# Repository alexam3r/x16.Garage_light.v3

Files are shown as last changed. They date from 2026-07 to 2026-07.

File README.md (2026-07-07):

# Гаражный свет на ESP8266

Прошивка для управления светом в гараже на базе ESP8266 (Wemos D1 mini).
Среда разработки — PlatformIO + Arduino framework, язык C++.

Устройство подключается к Wi-Fi и MQTT-брокеру, управляет двумя группами света
(основное освещение и декоративные лампы Эдисона) в двух взаимоисключающих
режимах, реагирует на PIR-датчик движения и раз в минуту публикует JSON-статус
с показаниями датчика температуры/влажности.

## Аппаратная часть

- **Контроллер:** Wemos D1 mini (ESP8266).
- **Питание:** БП 220VAC → 5VDC.
- **Реле:** плата с двумя электромеханическими реле (основное + Edison).
- **Датчики:** AM2320 (температура/влажность, I²C) и PIR (движение).

### Распиновка

| Пин | GPIO | Функция |
| --- | ---- | --- |
| D5  | GPIO14 | Основное освещение (реле 1) |
| D6  | GPIO12 | Декоративные лампы Эдисона (реле 2) |
| D7  | GPIO13 | PIR — датчик движения |
| D1  | GPIO5  | I²C SDA → AM2320 |
| D2  | GPIO4  | I²C SCL → AM2320 |

AM2320 питается от 3.3V; PIR и реле-плата — по своей логике (обычно 5V с общим GND).

## Возможности

- **PIR-автоматика:** при обнаружении движения свет включается на 10 минут;
  повторное срабатывание обнуляет таймер. Триггер — по фронту LOW→HIGH.
- **MQTT-управление:** команда `light/set ON` включает свет на 1 час.
- **Два режима света** (`mode`): `main` (D5) и `edison` (D6), взаимоисключающие.
  Команда `mode/set edison` при выключенном свете включает свет в режиме edison
  на 1 час; при горящем свете — переключает активную лампу, не трогая таймер.
- **Сброс при выключении:** когда свет гаснет (таймер истёк или `light/set OFF`),
  режим возвращается на `main`. Реакцией на PIR это не управляет — она задаётся
  только `motion/set` (с авто-возвратом через 6 часов).
- **Отключаемая реакция на PIR:** `motion/set OFF` — PIR перестаёт включать свет,
  но факт движения продолжает публиковаться в `motion/state`. Состояние самой
  реакции (вкл/выкл) отдаётся отдельным retain-топиком `motion/enabled` — чтобы
  клиенты (например Home Assistant) получали его мгновенно, без ожидания статуса.
  Реакция сама включается обратно через 6 часов (`MOTION_AUTO_ENABLE_MS`) — сброс
  к дефолту на случай, если ушёл из гаража и забыл вернуть; `motion/set ON`
  отменяет авто-возврат.
- **JSON-статус** в топике `status`: состояние света, режим, факт движения,
  включена ли реакция на PIR, температура, влажность, uptime, уровень Wi-Fi сигнала.
  Публикуется раз в минуту, а при изменении любого параметра состояния (свет,
  режим, движение, реакция на PIR) — немедленно, с обнулением минутного таймера
  (чтобы не слать статус дважды подряд).
- **Watchdog:** если Wi-Fi и MQTT одновременно отсутствуют 10 минут —
  устройство перезагружается (`ESP.restart()`). Аппаратный watchdog core ESP8266
  защищает от зависаний.

## Настройка

1. Скопируйте `src/Secrets.h.sample` в `src/Secrets.h` и заполните реальные значения:
   - `WIFI_SSID`, `WIFI_PASSWORD` — Wi-Fi сеть;
   - `MQTT_HOST` — IP/hostname брокера;
   - `MQTT_USER`, `MQTT_PASSWORD` — креды брокера (пусто = без auth);
   - `MQTT_CLIENT_ID` — уникальный ID клиента.
2. При необходимости отредактируйте `src/Config.h`:
   - `RELAY_ACTIVE_HIGH` — полярность реле (`1` = HIGH включает; если реле
     срабатывает «наоборот» — поставьте `0`);
   - `LIGHT_TIMEOUT_PIR_MS` / `LIGHT_TIMEOUT_MQTT_MS` — длительности таймера;
   - `CFG_ENABLE_AM2320` — `0`, если датчик не подключён (temp/humidity = `null`).
3. `Secrets.h` исключён из git (`.gitignore`) — не коммитить креды.

## Сборка и прошивка

```bash
# только компиляция (проверка сборки)
pio run

# компиляция + прошивка устройства через USB
pio run -t upload

# монитор последовательного порта (115200)
pio device monitor
```

## MQTT-топики

Корень дерева — `garage/light`.

| Топик | Направление | Payload | Retain | Назначение |
| --- | --- | --- | --- | --- |
| `garage/light/availability` | out | `online`/`offline` | да | LWT + статус на коннекте |
| `garage/light/light/set` | in | `ON`/`OFF` | — | команда включения/выключения |
| `garage/light/light/state` | out | `ON`/`OFF` | да | текущее состояние света |
| `garage/light/mode/set` | in | `main`/`edison` | — | команда выбора режима |
| `garage/light/mode/state` | out | `main`/`edison` | да | текущий режим |
| `garage/light/motion/set` | in | `ON`/`OFF` | — | включить/выключить реакцию на PIR |
| `garage/light/motion/state` | out | `ON`/`OFF` | нет | факт обнаружения движения (по фронту) |
| `garage/light/motion/enabled` | out | `ON`/`OFF` | да | состояние реакции на PIR (вкл/выкл) |
| `garage/light/status` | out | JSON | да | статус устройства (раз в минуту + при изменении состояния) |

### Пример JSON статуса

```json
{"light":"on","mode":"main","motion":"off","motion_enabled":"on","temperature":23.4,"humidity":55.0,"uptime":3600,"wifi_rssi":-67}
```

- `motion` — факт обнаружения движения PIR прямо сейчас (`on`/`off`).
- `motion_enabled` — включена ли реакция на PIR (`on`/`off`; `off` после `motion/set OFF`,
  сам вернётся в `on` через 6 часов).

При недоступном датчике: `"temperature":null,"humidity":null`.

## Проверка через mosquitto

```bash
# подписка на все топики устройства
mosquitto_sub -h <broker> -t 'garage/light/#' -v

# включить свет
mosquitto_pub -h <broker> -t 'garage/light/light/set' -m 'ON'

# выключить свет
mosquitto_pub -h <broker> -t 'garage/light/light/set' -m 'OFF'

# включить режим Edison (при выключенном свете — включит свет в edison на 1 час)
mosquitto_pub -h <broker> -t 'garage/light/mode/set' -m 'edison'

# отключить реакцию на PIR (сама включится через 6 часов)
mosquitto_pub -h <broker> -t 'garage/light/motion/set' -m 'OFF'

# вернуть реакцию на PIR вручную (отменяет авто-возврат)
mosquitto_pub -h <broker> -t 'garage/light/motion/set' -m 'ON'
```

## Логика таймера и режимов

- **Один таймер выключения** + флаг источника (`PIR` или `MQTT`).
- PIR при выключенном свете → включение на `LIGHT_TIMEOUT_PIR_MS` (10 мин), источник `PIR`.
- PIR при включённом свете → обнуление таймера на длительность **текущего**
  источника (PIR → 10 мин, MQTT → 1 час). Источник переключается только явной
  MQTT-командой (`light/set ON` или `mode/set`); PIR не переподчиняет MQTT-сеанс.
- `light/set ON` → источник `MQTT`, таймер 1 час.
- `mode/set` при горящем свете → переключение лампы, таймер не меняется.
- `mode/set` при выключенном свете → включение в выбранном режиме на 1 час.
- Выключение (таймер или `light/set OFF`) → режим `main`; реакция на PIR не меняется.
- `motion/set OFF` → реакция на PIR выключена; через `MOTION_AUTO_ENABLE_MS` (6 ч)
  включается сама. `motion/set ON` включает сразу и отменяет авто-возврат.

## Troubleshooting

- **`temperature`/`humidity` = `null`** — датчик AM2320 не отвечает. Проверьте
  подключение SDA/SCL (D1/D2), питание 3.3V, подтяжки I²C (4.7kΩ к 3.3V, если
  на модуле их нет). Для отладки логики без датчика поставьте `CFG_ENABLE_AM2320=0`.
- **Реле щёлкает «наоборот»** (ON выключает свет) — инвертируйте `RELAY_ACTIVE_HIGH`
  в `Config.h`.
- **PIR не срабатывает** — попробуйте `PIR_PIN_MODE INPUT_PULLUP` в `Config.h`
  (если датчик с открытым коллектором); проверьте питание PIR.
- **MQTT не подключается** — смотрите `mqtt.state()` в Serial-логе: `-2` = не удалось
  подключиться, `-4` = неверный логин/пароль, `2` = ID клиента занят.
- **Устройство перезагружается** — если Wi-Fi/MQTT отсутствуют 10 минут, это
  срабатывает connectivity-watchdog (нормально); если чаще — проверьте питание
  (brownout от индуктивных выбросов реле) и стабильность сети.

## Структура файлов

| Файл | Назначение |
| --- | --- |
| `src/main.cpp` | Вся логика: `setup()` + `loop()`, Wi-Fi/MQTT, свет, PIR, AM2320. |
| `src/Config.h` | Пины, константы времени, MQTT-дефолты, переключатели `CFG_ENABLE_*`. |
| `src/Secrets.h` | Wi-Fi/MQTT креды (в `.gitignore`, редактируется под устройство). |
| `src/Secrets.h.sample` | Шаблон секретов (в git). |
| `platformio.ini` | Окружение сборки PlatformIO. |
| `architecture.md` | Описание архитектуры и логики. |
| `README.md` | Этот файл. |

## Подробности архитектуры

См. [`architecture.md`](architecture.md) — блок-схема, конечный автомат света,
логика таймера/режимов, watchdog-уровни, MQTT-дерево и ограничения.

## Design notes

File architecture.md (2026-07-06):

# Архитектура прошивки гаражного света

## Обзор

ESP8266 (Wemos D1 mini) управляет двумя группами света по MQTT и PIR-датчику,
публикует статус и поддерживает автономность через watchdog-и. Вся логика — в
`src/main.cpp`; конфигурация в `src/Config.h`, креды в `src/Secrets.h`.

## Блок-схема

```
   ┌─────────┐     ┌───────────┐     ┌───────────────┐     ┌──────────────┐
   │  Wi-Fi  │────▶│   MQTT    │────▶│ onMqttMessage │────▶│  Действия    │
   │ connect │     │  connect  │     │   (callback)  │     │ turnLight*  │
   └─────────┘     │  + LWT    │     └───────────────┘     │ applyMode   │
                   │  + subs   │                           │ extendTimer │
                   └─────┬─────┘                           └──────┬───────┘
                         │ publish (retain)                       │
                         ▼                                        │
                  ┌───────────────┐    ┌────────────┐              │
                  │  MQTT-топики  │◀───│  pollPir   │◀─────────────┘
                  │  state/status │    │ (front)    │
                  └───────────────┘    └────────────┘
```

`loop()` неблокирующий: держит Wi-Fi/MQTT, опрашивает PIR, ведёт таймер света,
читает AM2320 в кэш, раз в минуту публикует JSON, проверяет connectivity-watchdog.

## Конечный автомат света

Свет описывается тремя величинами: `lightState` (on/off), `currentSource`
(`SRC_NONE`/`SRC_PIR`/`SRC_MQTT`) и `currentMode` (`MODE_MAIN`/`MODE_EDISON`).
Один таймер `lightOffAt` (deadline в `millis()`).

| Событие | Условие | Действие |
| --- | --- | --- |
| PIR-фронт LOW→HIGH | свет выключен, `motionEnabled` | `turnLightOn(PIR, mode)` — таймер 10 мин |
| PIR-фронт LOW→HIGH | свет горит, `motionEnabled` | `extendTimer()` — обнулить на длительность текущего источника |
| `light/set ON` | любое | `turnLightOn(MQTT, mode)` — источник MQTT, таймер 1 час |
| `light/set OFF` | любое | `turnLightOff()` — выключить, `mode→main`, `motionEnabled→true` |
| `mode/set X` | свет горит | `applyMode(X)` — переключить лампу, таймер/источник не трогать |
| `mode/set X` | свет выключен | `turnLightOn(MQTT, X)` — включить в режиме X на 1 час |
| `motion/set OFF` | любое | `motionEnabled=false` (без публикации флага) |
| Таймер истёк | `lightOffAt` прошёл | `turnLightOff()` |
| PIR-фронт (любой) | всегда | `publishMotionState()` (факт движения, без retain) |

### Роль источника в продлении таймера

`extendTimer()` ставит таймер на длительность **текущего** источника:
- `SRC_PIR` → `LIGHT_TIMEOUT_PIR_MS` (10 мин);
- `SRC_MQTT` → `LIGHT_TIMEOUT_MQTT_MS` (1 час).

Источник меняется только явной MQTT-командой. PIR не переподчиняет MQTT-сеанс —
если свет включён по MQTT на час, PIR лишь продлевает на час (не на 10 минут).

### `mode/set` — диаграмма решений

```
mode/set <X>
   │
   ├── свет горит? ─── ДА ──▶ applyMode(X) + publishModeState()
   │                            (таймер и источник не меняются)
   │
   └── НЕТ ───────────────▶ turnLightOn(MQTT, X)
                                (включить в режиме X на 1 час)
```

При любом выключении режим сбрасывается на `main` (в `turnLightOff()`).

## PIR: debounce и развязка «наблюдение vs реакция»

Опрос в `pollPir()` каждый цикл `loop()`:

1. Сырое чтение изменилось → перезапуск debounce-таймера, выход.
2. Сырое чтение стабильно, отличается от зафиксированного, debounce (`PIR_DEBOUNCE_MS`) истёк → фиксация фронта.
3. На любой фронт → `publishMotionState()` (факт движения).
4. Фронт LOW→HIGH: если `motionEnabled` — реакция (включение/продление света); если `!motionEnabled` — только публикация.

**Развязка:** `motion/state` (факт движения) публикуется всегда, независимо от
`motionEnabled`. `motionEnabled` влияет только на включение света. Это позволяет
наблюдать активность датчика даже при отключённой реакции.

Флаг `motionEnabled` намеренно **не публикуется** ни в каком retain-топике — это
разовая команда; сбрасывается в ON при выключении света; при рестарте — default ON.

## MQTT-дерево

Корень `garage/light`. Направление: `in` — подписка (команды), `out` — публикация.

| Топик | Напр. | Retain | Payload |
| --- | --- | --- | --- |
| `availability` | out | да | `online`/`offline` |
| `light/set` | in | — | `ON`/`OFF` |
| `light/state` | out | да | `ON`/`OFF` |
| `mode/set` | in | — | `main`/`edison` |
| `mode/state` | out | да | `main`/`edison` |
| `motion/set` | in | — | `ON`/`OFF` (флаг реакции) |
| `motion/state` | out | **нет** | `ON`/`OFF` (факт движения) |
| `status` | out | да | JSON (раз в минуту) |

**LWT:** в `connectMqtt()` регистрируется will-сообщение `availability=offline`
(retain). При корректной связи мы публикуем `availability=online` на коннекте.
При обрыве связи брокер сам публикует `offline`.

**Порядок в `connectMqtt()`:** подписки на `set`-топики → публикация актуального
состояния. Мы не подписаны на собственные `state`-топики, поэтому echo своих
retained не превращается в команды.

## Глобальные переменные

| Переменная | Тип | Назначение |
| --- | --- | --- |
| `lightState` | `bool` | свет вкл/выкл |
| `currentMode` | `LightMode` | `MODE_MAIN`/`MODE_EDISON` |
| `currentSource` | `LightSource` | `SRC_NONE`/`SRC_PIR`/`SRC_MQTT` |
| `lightOffAt` | `unsigned long` | deadline выключения (`millis()+timeout`), 0 = неактивен |
| `pirStable`/`pirRawLast`/`pirDebounceTs` | `bool`/`bool`/`unsigned long` | debounce PIR |
| `motionEnabled` | `bool` | реакция на PIR |
| `sensorOk`/`lastTemp`/`lastHum`/`lastSensorRead` | — | кэш AM2320 |
| `lastWifiAttempt`/`lastMqttAttempt`/`lastStatusPub` | `unsigned long` | тайминги loop |
| `lastAllOkTs` | `unsigned long` | connectivity watchdog |
| `statusBuf[256]` | `char[]` | буфер JSON-статуса |

## Порядок `setup()`

1. Serial (115200).
2. Пины реле → OUTPUT, `applyRelay(*, false)` (безопасное стартовое состояние).
3. PIR → `pinMode`, чтение начального состояния в `pirStable`/`pirRawLast`.
4. `WiFi.persistent(false)`, `WiFi.mode(WIFI_STA)`.
5. `Wire.begin(I2C_SDA, I2C_SCL)` — **до** `am2320.begin()`.
6. `am2320.begin()` (если `CFG_ENABLE_AM2320`).
7. `mqtt.setServer`/`setCallback`/`setBufferSize(512)`.
8. `lastAllOkTs = millis()` (база connectivity watchdog).
9. `connectWifi()` — первая попытка.

## Цикл `loop()`

1. Неблокирующий реконнект Wi-Fi (раз в `WIFI_RECONNECT_DELAY_MS`).
2. Неблокирующий реконнект MQTT (раз в `MQTT_RECONNECT_DELAY_MS`, только при Wi-Fi).
3. `mqtt.loop()` — только если подключены.
4. `pollPir()` — каждый цикл.
5. `handleLightTimer()` — каждый цикл.
6. `readAm2320()` — обновление кэша раз в `SENSOR_READ_INTERVAL_MS`.
7. `publishStatusJson()` — раз в `STATUS_INTERVAL_MS` (только при MQTT).
8. Connectivity watchdog (см. ниже).

## Watchdog — два уровня

### 1. Connectivity watchdog (программный)

`lastAllOkTs` обновляется каждый цикл, если `WiFi.status()==WL_CONNECTED &&
mqtt.connected()`. Если с момента последнего «всё ОК» прошло `CONNECT_TIMEOUT_MS`
(10 минут) — `ESP.restart()`. Работает параллельно с реконнектами, не блокирует их.

### 2. Аппаратный watchdog (core ESP8266)

ESP8266 core содержит два watchdog-таймера — software (SDK) и hardware
(финальная защита). Оба активны по умолчанию; их нужно регулярно «кормить»,
иначе — перезагрузка. Кормление происходит через:
- `yield()` / `delay()` — отдаёт управление Wi-Fi-стеку и кормит WDT;
- `mqtt.loop()`.

В долгих местах явно вызывается `yield()`: перед/после чтения AM2320
(I²C-транзакция ~0.5–1 с), после сборки JSON. `applyMode()` содержит
`delay(RELAY_SWITCH_DELAY_MS)`, который также кормит WDT и защищает от
индуктивного выброса реле. Отдельный `ESP.wdtEnable()` не используется —
core-WDT достаточен.

## Разностная форма `millis()` (защита от переполнения)

`millis()` переполняется через ~49.7 дней. Сравнение `millis() >= deadline`
**некорректно** при переполнении (deadline близко к концу цикла, `millis()`
обнулился). Вместо этого используется разностная арифметика `unsigned long`:

```
(millis() - lastXxx) >= INTERVAL
```

При переполнении разность `(unsigned long)(now - prev)` благодаря modular
арифметике даёт корректное значение. Все таймеры в `loop()` и `handleLightTimer()`
используют эту форму. `handleLightTimer()` дополнительно проверяет `lightOffAt != 0`.

## AM2320 — кэш-паттерн

Чтение датчика (~0.5–1 с с wake-up) вынесено из публикации статуса:
`readAm2320()` обновляет кэш `lastTemp`/`lastHum` раз в
`SENSOR_READ_INTERVAL_MS` (20 с), а `publishStatusJson()` публикует из кэша —
мгновенно. Валидация: `isnan()` + sanity-диапазон (`TEMP_MIN..TEMP_MAX`,
`HUM_MIN..HUM_MAX`); при ошибке — `NAN` → в JSON `null`. `Wire.begin()` вызывается
до `am2320.begin()` (библиотека не инициализирует Wire сама).

## JSON-статус

Топик `garage/light/status`, retain, раз в 60 с. Сборка через `dtostrf` +
конкатенация (без зависимости от float-printf). Поля:
`light`, `mode`, `motion`, `temperature`, `humidity`, `uptime`, `wifi_rssi`.
Недоступный датчик → `null`. Сборка в `statusBuf[256]` (вписывается в
`MQTT_MAX_PACKET_SIZE=512`).

## Безопасность и ограничения

- **Нет Home Assistant discovery** — только `set`/`state`/`availability` + JSON.
- **Нет OTA** — прошивка только по USB (`pio run -t upload`).
- **Нет persistence** — состояние сбрасывается при рестарте (свет выкл, режим
  `main`, `motionEnabled=true`); retained-сообщения обновляются при коннекте.
- **`cleanSession=true`** (PubSubClient default) — нет persistent session,
  очередь команд брокером не хранится.
- **Секреты не в git** — `Secrets.h` в `.gitignore`.
- **MQTT payload** — в `onMqttMessage` копируется в локальный буфер с нулём-
  терминатором перед парсингом (`byte*` не нуль-терминирован).
- **Публикация внутри callback** безопасна — payload уже скопирован; подписки
  выполняются только в `connectMqtt()`, не в callback.

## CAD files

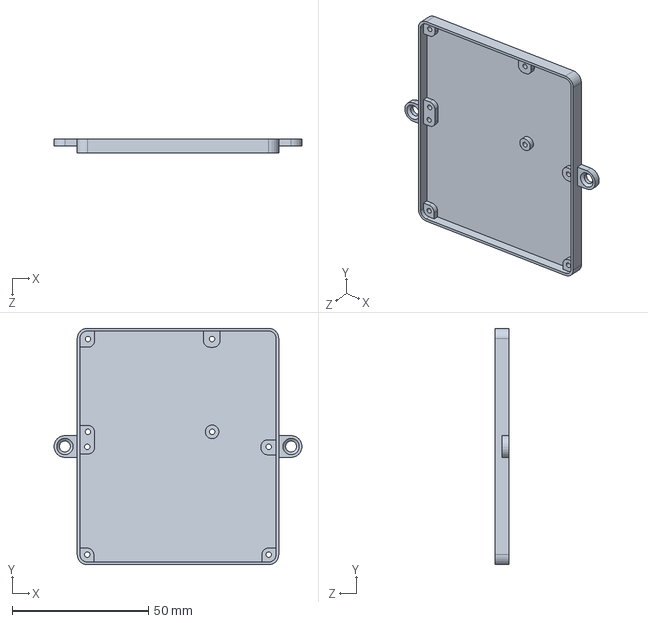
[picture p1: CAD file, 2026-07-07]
Altium/box_Mech.SLDPRT
90.9 x 86.7 x 5.00 mm

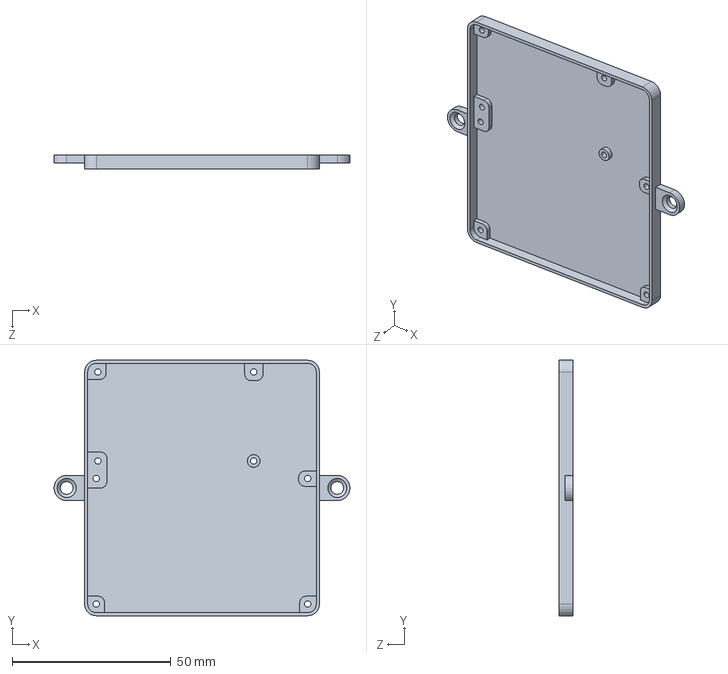
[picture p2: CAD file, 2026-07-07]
Altium/box_SSR.SLDPRT
93.1 x 80.4 x 4.50 mm

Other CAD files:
Altium/box_Mech.STL

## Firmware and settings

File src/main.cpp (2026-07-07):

// =============================================================================
// Прошивка гаражного света на ESP8266 (Wemos D1 mini).
//
// Назначение: управление двумя группами света (основная D5 / декоративная
// Edison D6) в двух взаимоисключающих режимах, с автоматикой по PIR-датчику,
// MQTT-командами, минутным JSON-статусом и отключаемой реакцией на движение.
//
// Вся логика ведётся в этом файле. Конфиг — Config.h, креды — Secrets.h.
// =============================================================================

#include <Arduino.h>
#include <ESP8266WiFi.h>
#include <PubSubClient.h>
#include <Wire.h>

#include "Config.h"   // должен идти ДО условного include AM2320 (содержит CFG_ENABLE_AM2320)
#include "Secrets.h"

#if CFG_ENABLE_AM2320
#include <Adafruit_AM2320.h>
#endif

// -----------------------------------------------------------------------------
// Глобальные объекты
// -----------------------------------------------------------------------------
WiFiClient     espClient;
PubSubClient   mqtt(espClient);
#if CFG_ENABLE_AM2320
Adafruit_AM2320 am2320;
#endif

// -----------------------------------------------------------------------------
// Режимы и источники света
// -----------------------------------------------------------------------------
enum LightMode   : uint8_t { MODE_MAIN = 0, MODE_EDISON = 1 };
enum LightSource : uint8_t { SRC_NONE = 0, SRC_PIR = 1, SRC_MQTT = 2 };

// -----------------------------------------------------------------------------
// Состояние
// -----------------------------------------------------------------------------
// Свет и таймер
bool          lightState    = false;   // вкл/выкл
LightMode     currentMode   = MODE_MAIN;
LightSource   currentSource = SRC_NONE;
unsigned long lightOffAt    = 0;       // deadline выключения (millis()+timeout), 0 = таймер неактивен

// PIR (опрос с антидребезгом по фронту)
bool          pirStable     = false;   // стабильное состояние после debounce
bool          pirRawLast    = false;   // последнее «сырое» чтение пина
unsigned long pirDebounceTs = 0;       // когда последний раз видели изменение
bool          motionEnabled = true;    // реакция на PIR (motion/set ON/OFF)
unsigned long motionEnableAt = 0;      // deadline авто-возврата реакции, 0 = таймер неактивен

// AM2320 (кэш значений — чтение развязано с публикацией статуса)
#if CFG_ENABLE_AM2320
bool          sensorOk      = false;
float         lastTemp      = NAN;
float         lastHum       = NAN;
unsigned long lastSensorRead = 0;
#endif

// Тайминги loop()
unsigned long lastWifiAttempt = 0;
unsigned long lastMqttAttempt = 0;
unsigned long lastStatusPub   = 0;
bool          statusDirty     = false;  // состояние изменилось — статус уйдёт немедленно

// Connectivity watchdog: последний момент, когда и Wi-Fi, и MQTT были подключены.
unsigned long lastAllOkTs     = 0;

// Буфер для JSON-статуса
char statusBuf[256];

// -----------------------------------------------------------------------------
// Прототипы функций
// -----------------------------------------------------------------------------
void applyRelay(uint8_t pin, bool on);
void applyMode(LightMode mode);
void turnLightOn(LightSource src, LightMode mode);
void turnLightOff();
void extendTimer();
void handleLightTimer();
void handleMotionTimer();
void pollPir();
void readAm2320();
void handleLightSet(const char* cmd);
void handleModeSet(const char* cmd);
void handleMotionSet(const char* cmd);
void onMqttMessage(char* topic, byte* payload, unsigned int length);
bool connectWifi();
bool connectMqtt();
void publishAvailability(bool online);
void publishLightState();
void publishModeState();
void publishMotionState();
void publishMotionEnabledState();
void publishStatusJson();

// =============================================================================
// Реле и режимы
// =============================================================================

// Инкапсулирует полярность управления реле.
void applyRelay(uint8_t pin, bool on) {
    digitalWrite(pin, RELAY_ACTIVE_HIGH ? on : !on);
}

// Зажигает пин активного режима, второй гасит. Режимы взаимоисключающие.
// Пауза между гашением и зажиганием — защита от индуктивного выброса реле.
void applyMode(LightMode mode) {
    applyRelay(PIN_LIGHT_MAIN, false);
    applyRelay(PIN_LIGHT_EDISON, false);
    delay(RELAY_SWITCH_DELAY_MS);   // также кормит core WDT
    if (mode == MODE_MAIN) {
        applyRelay(PIN_LIGHT_MAIN, true);
    } else {
        applyRelay(PIN_LIGHT_EDISON, true);
    }
    currentMode = mode;
}

// =============================================================================
// Логика света и таймера
// =============================================================================

// Включить свет от источника src в режиме mode, поставить таймер выключения.
void turnLightOn(LightSource src, LightMode mode) {
    currentSource = src;
    unsigned long timeout = (src == SRC_PIR) ? LIGHT_TIMEOUT_PIR_MS : LIGHT_TIMEOUT_MQTT_MS;
    lightOffAt  = millis() + timeout;
    lightState  = true;
    applyMode(mode);
    publishLightState();
    publishModeState();
    statusDirty = true;

    Serial.print(F("Light ON  src="));
    Serial.print(src == SRC_PIR ? F("PIR") : F("MQTT"));
    Serial.print(F(" mode="));
    Serial.print(mode == MODE_MAIN ? PAYLOAD_MODE_MAIN : PAYLOAD_MODE_EDISON);
    Serial.print(F(" timeout_ms="));
    Serial.println(timeout);
}

// Выключить свет, сбросить источник и режим на main.
// Реле гасятся напрямую (без applyMode — тот повторно зажёг бы реле режима).
// Флаг motionEnabled НЕ трогаем: реакция на PIR управляется только motion/set.
void turnLightOff() {
    lightState    = false;
    currentSource = SRC_NONE;
    lightOffAt    = 0;
    currentMode   = MODE_MAIN;   // режим по умолчанию (логически, без энергизации реле)
    applyRelay(PIN_LIGHT_MAIN, false);
    applyRelay(PIN_LIGHT_EDISON, false);
    publishLightState();
    publishModeState();
    statusDirty = true;

    Serial.println(F("Light OFF, mode reset to main"));
}

// Обнулить таймер на длительность текущего источника (PIR -> 10 мин, MQTT -> 1 ч).
void extendTimer() {
    if (!lightState) return;     // нечего продлевать
    unsigned long timeout = (currentSource == SRC_PIR) ? LIGHT_TIMEOUT_PIR_MS : LIGHT_TIMEOUT_MQTT_MS;
    lightOffAt = millis() + timeout;

    Serial.print(F("Timer extended to "));
    Serial.print(timeout);
    Serial.print(F(" ms (source="));
    Serial.print(currentSource == SRC_PIR ? F("PIR") : F("MQTT"));
    Serial.println(')');
}

// Проверка истечения таймера выключения. Разностная форма корректна через
// переполнение millis() (~49.7 дней).
void handleLightTimer() {
    if (lightOffAt == 0) return;
    if ((long)(millis() - lightOffAt) >= 0) {
        Serial.println(F("Timer expired"));
        turnLightOff();
    }
}

// =============================================================================
// PIR (опрос с антидребезгом по фронту)
// =============================================================================

void pollPir() {
    bool rawNow = digitalRead(PIN_PIR);

    // Сырое чтение изменилось — перезапускаем debounce-таймер.
    if (rawNow != pirRawLast) {
        pirRawLast    = rawNow;
        pirDebounceTs = millis();
        return;
    }

    // Сырое чтение стабильно и отличается от зафиксированного состояния,
    // debounce истёк — фиксируем новый фронт.
    if (rawNow != pirStable && (millis() - pirDebounceTs) >= PIR_DEBOUNCE_MS) {
        bool prev = pirStable;
        pirStable = rawNow;

        // Факт движения публикуем всегда (развязка «наблюдение vs реакция»).
        publishMotionState();
        statusDirty = true;

        // Фронт LOW -> HIGH: движение началось.
        if (!prev && pirStable) {
            Serial.println(F("PIR: motion START"));
            if (motionEnabled) {
                if (!lightState) {
                    turnLightOn(SRC_PIR, currentMode);   // свет был выключен — включаем на 10 мин
                } else {
                    extendTimer();                        // свет горит — обнуляем таймер текущего источника
                }
            } else {
                Serial.println(F("  motion disabled, no action"));
            }
        } else if (prev && !pirStable) {
            // Фронт HIGH -> LOW: движение закончилось — только публикация (уже сделана).
            Serial.println(F("PIR: motion END"));
        }
    }
}

// =============================================================================
// AM2320 (кэш значений)
// =============================================================================

void readAm2320() {
#if CFG_ENABLE_AM2320
    if (!sensorOk) return;
    if ((millis() - lastSensorRead) < SENSOR_READ_INTERVAL_MS) return;
    lastSensorRead = millis();

    yield();   // кормит core WDT перед долгим I²C-чтением (~0.5–1 с)
    float t = am2320.readTemperature();
    float h = am2320.readHumidity();
    yield();

    // Валидация: isnan + sanity-диапазон.
    if (!isnan(t) && t >= TEMP_MIN && t <= TEMP_MAX) {
        lastTemp = t;
    } else {
        lastTemp = NAN;
    }
    if (!isnan(h) && h >= HUM_MIN && h <= HUM_MAX) {
        lastHum = h;
    } else {
        lastHum = NAN;
    }

    if (isnan(lastTemp) || isnan(lastHum)) {
        Serial.println(F("AM2320: read failed"));
    }
#endif
}

// =============================================================================
// Обработка MQTT-команд
// =============================================================================

void handleLightSet(const char* cmd) {
    if (strcasecmp(cmd, PAYLOAD_ON) == 0) {
        turnLightOn(SRC_MQTT, currentMode);
    } else if (strcasecmp(cmd, PAYLOAD_OFF) == 0) {
        turnLightOff();
    } else {
        Serial.print(F("light/set: unknown payload: "));
        Serial.println(cmd);
    }
}

void handleModeSet(const char* cmd) {
    LightMode target;
    if (strcasecmp(cmd, PAYLOAD_MODE_MAIN) == 0) {
        target = MODE_MAIN;
    } else if (strcasecmp(cmd, PAYLOAD_MODE_EDISON) == 0) {
        target = MODE_EDISON;
    } else {
        Serial.print(F("mode/set: unknown payload: "));
        Serial.println(cmd);
        return;
    }

    if (lightState) {
        // Свет горит — переключить активный пин, таймер и источник не трогать.
        applyMode(target);
        publishModeState();
        statusDirty = true;
        Serial.print(F("Mode switched (light on) -> "));
        Serial.println(target == MODE_MAIN ? PAYLOAD_MODE_MAIN : PAYLOAD_MODE_EDISON);
    } else {
        // Свет выключен — включить в выбранном режиме на 1 час (источник MQTT).
        turnLightOn(SRC_MQTT, target);
    }
}

void handleMotionSet(const char* cmd) {
    if (strcasecmp(cmd, PAYLOAD_ON) == 0) {
        motionEnabled  = true;
        motionEnableAt = 0;          // авто-возврат больше не нужен
        Serial.println(F("Motion reaction: ON"));
    } else if (strcasecmp(cmd, PAYLOAD_OFF) == 0) {
        motionEnabled  = false;
        motionEnableAt = millis() + MOTION_AUTO_ENABLE_MS;   // сам включится через 6 ч
        Serial.println(F("Motion reaction: OFF (auto-enable in 6h)"));
    } else {
        Serial.print(F("motion/set: unknown payload: "));
        Serial.println(cmd);
        return;
    }
    // Состояние реакции публикуем отдельным retain-топиком (без задержки статуса).
    publishMotionEnabledState();
    statusDirty = true;
}

// Авто-возврат реакции на PIR: если её отключили и прошло MOTION_AUTO_ENABLE_MS,
// снова включаем (сброс к дефолту). Разностная форма корректна через overflow millis().
void handleMotionTimer() {
    if (motionEnableAt == 0) return;
    if ((long)(millis() - motionEnableAt) >= 0) {
        motionEnabled  = true;
        motionEnableAt = 0;
        Serial.println(F("Motion reaction: auto-enabled after timeout"));
        publishMotionEnabledState();
        statusDirty = true;
    }
}

void onMqttMessage(char* topic, byte* payload, unsigned int length) {
    if (!mqtt.connected()) return;
    if (length == 0) return;   // пустой payload игнорируем

    // payload не нуль-терминирован — копируем в локальный буфер с '\0'.
    char buf[16];
    size_t n = (length < sizeof(buf) - 1) ? length : (sizeof(buf) - 1);
    memcpy(buf, payload, n);
    buf[n] = '\0';

    Serial.print(F("[MQTT] "));
    Serial.print(topic);
    Serial.print(F(" => "));
    Serial.println(buf);

    // Роутинг по топику. Публикации внутри callback безопасны — payload уже скопирован.
    if (strcmp(topic, TOPIC_LIGHT_SET) == 0) {
        handleLightSet(buf);
    } else if (strcmp(topic, TOPIC_MODE_SET) == 0) {
        handleModeSet(buf);
    } else if (strcmp(topic, TOPIC_MOTION_SET) == 0) {
        handleMotionSet(buf);
    }
}

// =============================================================================
// Подключение Wi-Fi и MQTT
// =============================================================================

bool connectWifi() {
    if (WiFi.status() == WL_CONNECTED) return true;

    Serial.print(F("Wi-Fi: connecting to "));
    Serial.println(WIFI_SSID);

    // WiFi.mode/ persistent уже выставлены в setup().
    WiFi.begin(WIFI_SSID, WIFI_PASSWORD);

    // Ждём подключения ~10 секунд (20 × 500 мс).
    uint8_t attempts = 0;
    while (WiFi.status() != WL_CONNECTED && attempts++ < 20) {
        delay(500);
        Serial.print('.');
    }
    Serial.println();

    if (WiFi.status() == WL_CONNECTED) {
        Serial.print(F("Wi-Fi: connected, IP="));
        Serial.println(WiFi.localIP());
        return true;
    }

    Serial.println(F("Wi-Fi: connection failed"));
    return false;
}

bool connectMqtt() {
    Serial.print(F("MQTT: connecting to "));
    Serial.print(MQTT_HOST);
    Serial.print(':');
    Serial.println(MQTT_PORT);

    // LWT: при потере связи брокер сам опубликует availability=offline (retain).
    bool ok;
    if (strlen(MQTT_USER) > 0) {
        ok = mqtt.connect(MQTT_CLIENT_ID, MQTT_USER, MQTT_PASSWORD,
                          TOPIC_AVAILABILITY, 0, true, PAYLOAD_OFFLINE);
    } else {
        ok = mqtt.connect(MQTT_CLIENT_ID, nullptr, nullptr,
                          TOPIC_AVAILABILITY, 0, true, PAYLOAD_OFFLINE);
    }

    if (!ok) {
        Serial.print(F("MQTT: failed, rc="));
        Serial.println(mqtt.state());   // 4 = bad creds, -2 = connect failed, ...
        return false;
    }

    Serial.println(F("MQTT: connected"));

    // Сначала подписки, затем публикация состояния — чтобы не получить собственные
    // retained обратно как команды (мы не подписаны на state-топики).
    mqtt.subscribe(TOPIC_LIGHT_SET);
    mqtt.subscribe(TOPIC_MODE_SET);
    mqtt.subscribe(TOPIC_MOTION_SET);
    Serial.println(F("MQTT: subscribed to set-topics"));

    // Публикуем актуальное состояние (retain, кроме motion/state).
    publishAvailability(true);
    publishLightState();
    publishModeState();
    publishMotionState();
    publishMotionEnabledState();
    statusDirty = true;   // свежий статус сразу после (пере)подключения
    return true;
}

// =============================================================================
// Публикации
// =============================================================================

void publishAvailability(bool online) {
    if (!mqtt.connected()) return;
    mqtt.publish(TOPIC_AVAILABILITY, online ? PAYLOAD_ONLINE : PAYLOAD_OFFLINE, true);
}

void publishLightState() {
    if (!mqtt.connected()) return;
    mqtt.publish(TOPIC_LIGHT_STATE, lightState ? PAYLOAD_ON : PAYLOAD_OFF, true);
}

void publishModeState() {
    if (!mqtt.connected()) return;
    mqtt.publish(TOPIC_MODE_STATE,
                 currentMode == MODE_MAIN ? PAYLOAD_MODE_MAIN : PAYLOAD_MODE_EDISON, true);
}

// Факт движения — без retain (публикация только по фронту).
void publishMotionState() {
    if (!mqtt.connected()) return;
    mqtt.publish(TOPIC_MOTION_STATE, pirStable ? PAYLOAD_ON : PAYLOAD_OFF, false);
}

// Состояние реакции на PIR — retain (HA читает мгновенно, без ожидания статуса).
void publishMotionEnabledState() {
    if (!mqtt.connected()) return;
    mqtt.publish(TOPIC_MOTION_ENABLED, motionEnabled ? PAYLOAD_ON : PAYLOAD_OFF, true);
}

// JSON-статус (раз в минуту + немедленно при изменении состояния): light, mode,
// motion, motion_enabled, temperature, humidity, uptime, wifi_rssi.
// Сборка через dtostrf + конкатенация — без зависимости от float-printf.
void publishStatusJson() {
    if (!mqtt.connected()) return;

    char num[12];

    strcpy(statusBuf, "{\"light\":\"");
    strcat(statusBuf, lightState ? "on" : "off");
    strcat(statusBuf, "\",\"mode\":\"");
    strcat(statusBuf, currentMode == MODE_MAIN ? "main" : "edison");
    strcat(statusBuf, "\",\"motion\":\"");
    strcat(statusBuf, pirStable ? "on" : "off");
    strcat(statusBuf, "\",\"motion_enabled\":\"");
    strcat(statusBuf, motionEnabled ? "on" : "off");
    strcat(statusBuf, "\",\"temperature\":");

#if CFG_ENABLE_AM2320
    if (isnan(lastTemp)) {
        strcat(statusBuf, "null");
    } else {
        dtostrf(lastTemp, 2, 1, num);
        strcat(statusBuf, num);
    }
#else
    strcat(statusBuf, "null");
#endif
    strcat(statusBuf, ",\"humidity\":");
#if CFG_ENABLE_AM2320
    if (isnan(lastHum)) {
        strcat(statusBuf, "null");
    } else {
        dtostrf(lastHum, 2, 1, num);
        strcat(statusBuf, num);
    }
#else
    strcat(statusBuf, "null");
#endif

    strcat(statusBuf, ",\"uptime\":");
    utoa((unsigned)(millis() / 1000UL), num, 10);
    strcat(statusBuf, num);

    strcat(statusBuf, ",\"wifi_rssi\":");
    int rssi = WiFi.RSSI();
    if (WiFi.status() == WL_CONNECTED) {
        itoa(rssi, num, 10);
        strcat(statusBuf, num);
    } else {
        strcat(statusBuf, "null");
    }
    strcat(statusBuf, "}");

    yield();
    mqtt.publish(TOPIC_STATUS, statusBuf, true);
}

// =============================================================================
// setup / loop
// =============================================================================

void setup() {
    Serial.begin(115200);
    delay(100);
    Serial.println();
    Serial.println(F("=== Garage light (ESP8266) ==="));

    // Пины реле — выходы, безопасное стартовое состояние (выключено).
    pinMode(PIN_LIGHT_MAIN, OUTPUT);
    pinMode(PIN_LIGHT_EDISON, OUTPUT);
    applyRelay(PIN_LIGHT_MAIN, false);
    applyRelay(PIN_LIGHT_EDISON, false);

    // PIR.
    pinMode(PIN_PIR, PIR_PIN_MODE);
    pirStable  = digitalRead(PIN_PIR);
    pirRawLast = pirStable;

    // Wi-Fi: только STA, без записи в flash при каждом begin.
    WiFi.persistent(false);
    WiFi.mode(WIFI_STA);

    // I²C для AM2320 (Wire.begin ДО am2320.begin()).
    Wire.begin(I2C_SDA, I2C_SCL);

#if CFG_ENABLE_AM2320
    sensorOk = am2320.begin();
    Serial.print(F("AM2320: "));
    Serial.println(sensorOk ? F("initialized") : F("not found"));
#else
    Serial.println(F("AM2320: disabled (CFG_ENABLE_AM2320=0)"));
#endif

    // MQTT.
    mqtt.setServer(MQTT_HOST, MQTT_PORT);
    mqtt.setCallback(onMqttMessage);
    mqtt.setBufferSize(MQTT_BUFFER_SIZE);

    lastAllOkTs = millis();   // базовая точка для connectivity watchdog

    connectWifi();            // первый запуск — пробуем сразу
}

void loop() {
    unsigned long now = millis();

    // --- Неблокирующее восстановление Wi-Fi ---
    if (WiFi.status() != WL_CONNECTED) {
        if ((now - lastWifiAttempt) >= WIFI_RECONNECT_DELAY_MS) {
            lastWifiAttempt = now;
            connectWifi();
        }
    }

    // --- Неблокирующее восстановление MQTT ---
    if (WiFi.status() == WL_CONNECTED && !mqtt.connected()) {
        if ((now - lastMqttAttempt) >= MQTT_RECONNECT_DELAY_MS) {
            lastMqttAttempt = now;
            if (connectMqtt()) {
                lastMqttAttempt = 0;   // сразу ретраить при следующем сбое
            }
        }
    }

    // --- Обработка входящих MQTT-пакетов ---
    if (mqtt.connected()) {
        mqtt.loop();
    }

    // --- Основная логика ---
    pollPir();
    handleLightTimer();
    handleMotionTimer();
    readAm2320();

    // --- JSON-статус: раз в минуту либо немедленно при изменении состояния.
    // Немедленная отправка обнуляет минутный таймер — без дублей подряд.
    if (mqtt.connected() && (statusDirty || (millis() - lastStatusPub) >= STATUS_INTERVAL_MS)) {
        statusDirty   = false;
        lastStatusPub = millis();
        publishStatusJson();
    }

    // --- Connectivity watchdog: 10 минут без Wi-Fi+MQTT -> restart ---
    if (WiFi.status() == WL_CONNECTED && mqtt.connected()) {
        lastAllOkTs = millis();
    } else if ((millis() - lastAllOkTs) >= CONNECT_TIMEOUT_MS) {
        Serial.println(F("Watchdog: no Wi-Fi+MQTT for 10 min, restarting..."));
        delay(200);   // успеть отправить лог
        ESP.restart();
    }
}

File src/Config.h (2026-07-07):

#pragma once

// =============================================================================
// Конфигурация прошивки гаражного света (ESP8266, Wemos D1 mini).
// Здесь НЕТ секретов — креды лежат в Secrets.h.
// =============================================================================

// -----------------------------------------------------------------------------
// Пины (распиновка Wemos D1 mini)
// -----------------------------------------------------------------------------
#define PIN_LIGHT_MAIN     D5   // GPIO14 — основное освещение (реле 1)
#define PIN_LIGHT_EDISON   D6   // GPIO12 — декоративные лампы Эдисона (реле 2)
#define PIN_PIR            D7   // GPIO13 — датчик движения (PIR)

#define I2C_SDA            D2   // GPIO4 — I²C SDA (AM2320)
#define I2C_SCL            D1   // GPIO5 — I²C SCL (AM2320)

// -----------------------------------------------------------------------------
// Реле
// -----------------------------------------------------------------------------
// Полярность управления реле. 1: HIGH = включено (active-HIGH модуль);
// 0: LOW = включено (active-LOW модуль). Инвертируется в applyRelay().
#define RELAY_ACTIVE_HIGH       1
// Пауза между гашением одного реле и зажиганием другого при переключении
// режима — защита от индуктивного выброса и brownout ESP8266.
#define RELAY_SWITCH_DELAY_MS   10

// -----------------------------------------------------------------------------
// PIR (датчик движения)
// -----------------------------------------------------------------------------
// INPUT — для PIR с активным выходом (HC-SR501 и клоны).
// Если сигнал плавает (открытый коллектор) — заменить на INPUT_PULLUP.
#define PIR_PIN_MODE            INPUT
#define PIR_DEBOUNCE_MS         50   // антидребезг PIR, мс
// Авто-возврат реакции на PIR: если её отключили командой motion/set OFF,
// через это время реакция сама включится (сброс к дефолту, если ушёл из гаража).
#define MOTION_AUTO_ENABLE_MS   21600000UL   // 6 часов

// -----------------------------------------------------------------------------
// Таймеры света
// -----------------------------------------------------------------------------
#define LIGHT_TIMEOUT_PIR_MS    600000UL    // 10 минут — источник PIR
#define LIGHT_TIMEOUT_MQTT_MS   3600000UL   // 1 час   — источник MQTT

// -----------------------------------------------------------------------------
// Интервалы loop()
// -----------------------------------------------------------------------------
#define STATUS_INTERVAL_MS      60000UL     // публикация JSON-статуса раз в минуту
#define SENSOR_READ_INTERVAL_MS 20000UL     // обновление кэша AM2320 (>= 2 с минимум датчика)
#define WIFI_RECONNECT_DELAY_MS 10000UL     // задержка между попытками Wi-Fi
#define MQTT_RECONNECT_DELAY_MS 5000UL      // задержка между попытками MQTT
#define CONNECT_TIMEOUT_MS      600000UL    // connectivity watchdog: 10 минут без Wi-Fi+MQTT -> ESP.restart()

// -----------------------------------------------------------------------------
// MQTT
// -----------------------------------------------------------------------------
#define MQTT_BUFFER_SIZE        512         // PubSubClient::setBufferSize()
#define MQTT_PORT               1883

// -----------------------------------------------------------------------------
// Топики (корень garage/light, одно устройство)
// -----------------------------------------------------------------------------
#define TOPIC_AVAILABILITY      "garage/light/availability"   // retain: online/offline (LWT)
#define TOPIC_LIGHT_SET         "garage/light/light/set"      // cmd: ON/OFF
#define TOPIC_LIGHT_STATE       "garage/light/light/state"    // retain: ON/OFF
#define TOPIC_MODE_SET          "garage/light/mode/set"       // cmd: main/edison
#define TOPIC_MODE_STATE        "garage/light/mode/state"     // retain: main/edison
#define TOPIC_MOTION_SET        "garage/light/motion/set"     // cmd: ON/OFF (enable/disable реакции)
#define TOPIC_MOTION_STATE      "garage/light/motion/state"   // без retain: ON/OFF факт движения
#define TOPIC_MOTION_ENABLED    "garage/light/motion/enabled" // retain: ON/OFF состояние реакции на PIR
#define TOPIC_STATUS            "garage/light/status"         // retain: JSON раз в минуту

// -----------------------------------------------------------------------------
// Payload-константы
// -----------------------------------------------------------------------------
#define PAYLOAD_ON              "ON"
#define PAYLOAD_OFF             "OFF"
#define PAYLOAD_ONLINE          "online"
#define PAYLOAD_OFFLINE         "offline"
#define PAYLOAD_MODE_MAIN       "main"
#define PAYLOAD_MODE_EDISON     "edison"
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

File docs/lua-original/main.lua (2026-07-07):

function createLightTimer()
    if not lightTimer then
        lightTimer = tmr.create()
        lightTimer:register(dat.lightTimeout*1000, tmr.ALARM_SINGLE, function() 
            light("OFF")
            destroyLightTimer()
            dat.lightSelected = 'MAIN'
            table.insert(topub, {'lightSelected', dat.lightSelected})
        end)
        lightTimer:start()
    else
        lightTimer:stop()
        lightTimer:interval(dat.lightTimeout*1000)
        lightTimer:start()
    end
end

function destroyLightTimer()
    if(lightTimer) then
        lightTimer:stop()
        lightTimer:unregister()
        lightTimer = nil
    end
end

function createMoveDetectionTimer()
    if not moveDetectionTimer then
        moveDetectionTimer = tmr.create()
        moveDetectionTimer:register(dat.moveDetectionTimout, tmr.ALARM_SINGLE, function() -- (6870947) 1:54:30.947
            gpio.trig(pinPIR, "up", moveDetected)
            dat.lightSelected = 'MAIN'
            table.insert(topub, {'lightSelected', dat.lightSelected})
            dat.lightMoveDetection = 'ON'
            table.insert(topub, {'lightMoveDetection', dat.lightMoveDetection})
            destroyMoveDetectionTimer()
        end)
        moveDetectionTimer:start()
    else
        moveDetectionTimer:stop()
        moveDetectionTimer:interval(dat.moveDetectionTimout) --6870947
        moveDetectionTimer:start()
    end
end

function destroyMoveDetectionTimer()
    if(moveDetectionTimer) then
        moveDetectionTimer:stop()
        moveDetectionTimer:unregister()
        moveDetectionTimer = nil
    end
end

function light(_light)
    if dat.lightNow ~= _light then
        table.insert(topub, {'lightNow', _light})
    end
    dat.lightNow = _light
    if dat.lightNow == "ON" then
        if dat.lightSelected == 'MAIN' then
            gpio.write(pinLightMain,1)
            gpio.write(pinLightEdison,0)
        else
            gpio.write(pinLightMain,0)
            gpio.write(pinLightEdison,1)
        end
        createLightTimer()
        print('Light ON')
    else
        print('Light OFF')
        if dat.lightSelected == 'MAIN' then
            gpio.write(pinLightMain,0)
        else
            gpio.write(pinLightEdison,0)
        end
        dat.light = 'OFF'
        table.insert(topub, {'light', dat.light})
        destroyLightTimer()
    end
end

function moveDetected()
    print("MOVE!!!")
    if dat.lightNow == "ON" then
        createLightTimer()
    else
        dat.lightTimeout = 600
        createLightTimer()
        light("ON")
    end
end

gpio.trig(pinPIR, "up", moveDetected)

dofile("check_air_temp.lua")
tmr.create():alarm(1000, tmr.ALARM_AUTO,  function()
    dat.count = dat.count + 1

    if dat.count == 30 and not lightTimer then
        gpio.write(pinLightMain,0)
    end
    
    if dat.count >= 60 then
        table.insert(topub, {dat.clntid..'/heap', node.heap()})
        local uptime = rtctime.get()
        table.insert(topub, {dat.clntid..'/uptime', uptime})
--        if table.getn(dat.gasLastValues) >= 5 then
--            table.insert(topub, {'gas', getAvgTable(dat.gasLastValues)})
--        end
        dofile("check_air_temp.lua")
        dat.count = 0
        if dat.error_no > 100 then node.restart() end
    end
    if (topub and #topub ~= 0) then dofile 'mqttpub.lua' end
end) 

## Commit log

2026-07-06 fix: свет не гас при light/set=OFF и самосброс реакции на PIR
    - turnLightOff() больше не вызывает applyMode(MODE_MAIN), который
    повторно зажигал main-реле; реле гасятся напрямую applyRelay(..., false),
    режим сбрасывается в main логически
    - убран сброс motionEnabled в turnLightOff() — реакцией на PIR теперь
    управляет только motion/set
    - Config.h: исправлены комментарии GPIO у I2C (D2=GPIO4, D1=GPIO5)
    [Config.h, main.cpp]
2026-07-06 feat: авто-возврат реакции на PIR через 6ч + поле motion_enabled в статусе
    - motion/set OFF ставит таймер авто-возврата; через MOTION_AUTO_ENABLE_MS (6ч)
    реакция на PIR включается сама (сброс к дефолту, если ушёл из гаража).
    motion/set ON включает сразу и отменяет авто-возврат
    - новое поле "motion_enabled" в JSON-статусе (состояние реакции on/off)
    - README: описан авто-возврат, пояснение motion vs motion_enabled,
    примеры mosquitto, актуализирована логи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
2026-07-07 feat: retain-топик motion/enabled + конфиг Home Assistant
    Состояние реакции на PIR теперь публикуется отдельным retain-топиком
    garage/light/motion/enabled — клиенты (в т.ч. Home Assistant) получают
    его мгновенно, без ожидания минутного JSON-статуса. Добавлен фикс
    handleMotionSet (return при неизвестном payload) и YAML-конфиг MQTT
    сущностей для HA (light/select/switch) в homeassistant/garage_light.yaml.
2026-07-07 feat: немедленная отправка status при изменении состояния
    Раньше JSON-статус уходил строго раз в минуту. Теперь дополнительно
    публикуется сразу при изменении света/режима/движения/реакции на PIR
    (флаг statusDirty), с обнулением минутного таймера — статус не дублируется
    подряд.
2026-07-07 Добавлен проект устройства в Altium Designer, добавлены настройки среды разработки Visual Studio Code для работы с проектом.
2026-07-07 Добавлен проект Altium Designer для гаражного контроллера, а также скрипты на Lua для работы с MQTT и проверки температуры воздуха.
    [PCB1.PcbDoc, PCB2.PcbDoc, PCB3.PcbDoc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]
